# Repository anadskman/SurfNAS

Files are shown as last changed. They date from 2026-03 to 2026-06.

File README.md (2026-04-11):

# SurfNAS
A simple NAS ran by a raspberry pi

## How To Run
To Use this youll have to run a few commands in terminal first and download Raspberry Pi OS

### Install Libraries
Install [Raspberry Pi OS](https://downloads.raspberrypi.com/raspios_arm64/images/raspios_arm64-2025-12-04/2025-12-04-raspios-trixie-arm64.img.xz)
Open Terminal and Run
```
sudo apt update
sudo apt install python3-pip git
```
Then  Install Libraries
```
pip3 install adafruit-circuitpython-neopixel
pip3 install adafruit-circuitpython-ssd1306
pip3 install psutil
pip3 install pillow
```
This will Control
- OLED
- RGB LED
- system stats

### Enable I2C for the OLED
Run
```
sudo raspi-config
```
Then
```
Interface Options
→ I2C
→ Enable
```

### Run the Firmware
Make sure youve install [Nano SurfNAS.py](https://github.com/anadskman/SurfNAS/blob/main/Software/nano%20surfnas.py)

```
python3 surfnas.py
```
This Should Happen
- OLED showing stats
- LED changing color
- button shuts down system

### Start It Automatically
Create a systemd service
```
sudo nano /etc/systemd/system/surfnas.service
```
Paste
```
[Unit]
Description=SurfNAS Display Service
After=multi-user.target

[Service]
ExecStart=/usr/bin/python3 /home/pi/surfnas.py
Restart=always
User=pi

[Install]
WantedBy=multi-user.target
```
Enable It
```
sudo systemctl enable surfnas
sudo systemctl start surfnas
```
### What SurfNAS Should Show
OLED screen:
- SurfNAS
- CPU: 23%
- RAM: 41%
- Disk: 18%

LED:
| **Color** | **Meaning**
| :---: | :---:
| Green	| normal
| Orange | moderate load
| Red	heavy | load

Button:
- Power Control

## BOM
| Name | Description | URL | QTY | Price(€)
| :--: | :---: | :-: | :-: | :-----:
| Raspberry Pi Zero 2 WH | To Run the Server | [Amazon](https://www.amazon.ie/Raspberry-Pi-Zero-2-WH/dp/B0DB2JBD9C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) | 1 | 24.55
| MicroSD Card | 32GB | [Aliexpress](https://www.aliexpress.com/item/1005005262472106.html) | 1 | 6.66
| SSD | 128GB USB 3.0 | [Amazon](https://www.amazon.ie/gp/product/B0C1SD95B7/ref=ox_sc_act_title_2?smid=A22S87YMRWR0XZ&psc=1) | 1 | 20.99
| OLED | 0.96 I2C | [Aliexpress](https://www.aliexpress.com/item/1005006141235306.html) | 1 | 2.63
| Fan | 30mm Cooling Fan | [Amazon](https://www.amazon.ie/gp/product/B0DGG94SVD/ref=ox_sc_act_title_1?smid=A2LZP99XORN4MN&psc=1) | 1 | 5.78
| Button | Red Push Button 2 Pin | [Aliexpress](https://www.aliexpress.com/item/10000274959292.html) | 1 | 1.61
| RGB LED | SK6812MINI-E | Owned - Reuse From Hackpad Kit | 1 | 0.00
| Heat Sink | Blue kit | [Aliexpress](https://www.aliexpress.com/item/1005003083830470.html) | 1 | 2.36
| USB Adapter | C to Micro | [Amazon](https://www.amazon.ie/gp/product/B08WM1ZFZR/ref=ox_sc_act_title_2?smid=A2QHQAREJ10JUZ&psc=1) | 1 | 3.66
|  |  |  | Shipping | 4.89
|  |  |  | Total | 73.13

## Images
| Schematic | Case | Finished Look
| :---: | :---: | :---:
|  |  | 
)

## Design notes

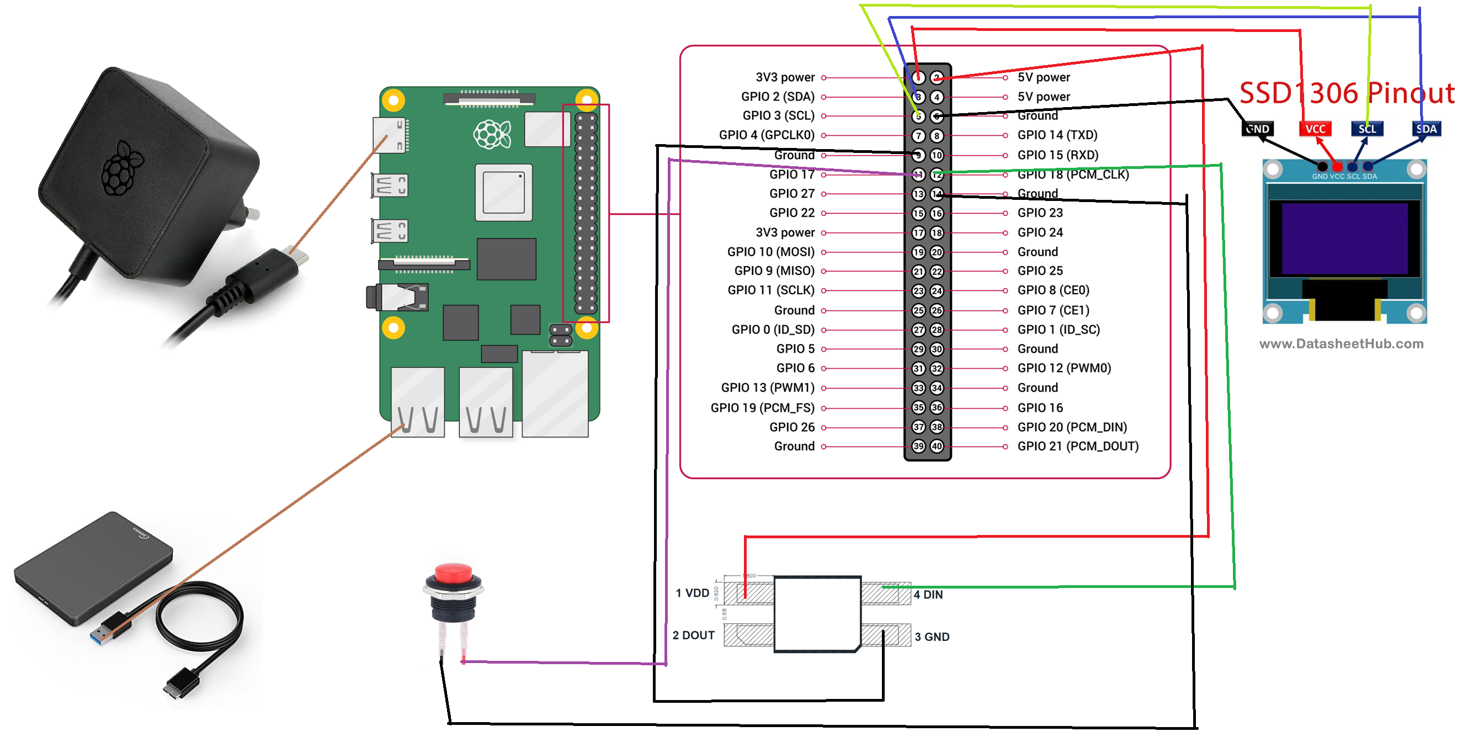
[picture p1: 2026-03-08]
SurfNAS diagram.png

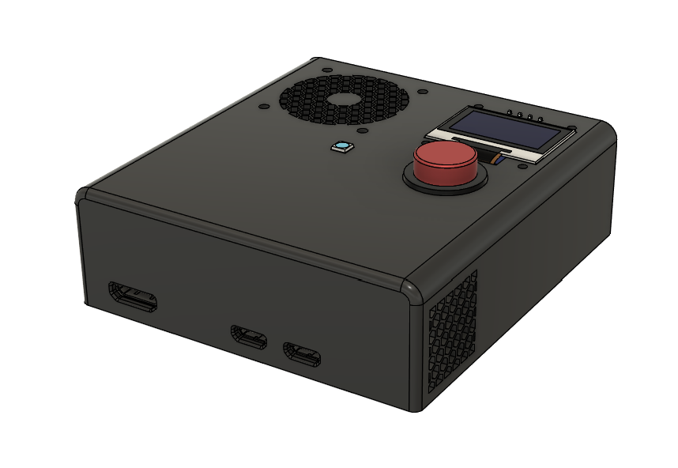
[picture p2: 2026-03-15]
Screenshot 2026-03-15 230135.png

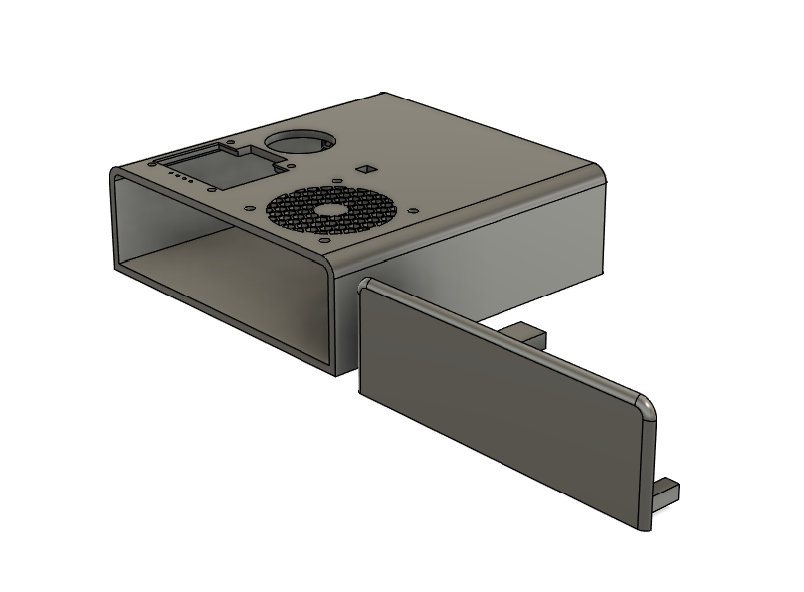
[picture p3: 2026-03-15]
Screenshot 2026-03-15 224113.png

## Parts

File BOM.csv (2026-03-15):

Name | Description | URL | Qty | Price(€)
Raspberry Pi Zero 2 WH | To Run the Server | https://www.amazon.ie/Raspberry-Pi-Zero-2-WH/dp/B0DB2JBD9C?s=electronics | 1 | 24.55
MicroSD Card | 32GB | https://www.aliexpress.com/item/1005005262472106.html | 1 | 6.66
SSD | 128GB USB 3.0 | https://www.amazon.ie/gp/product/B0C1SD95B7/ref=ox_sc_act_title_2?smid=A22S87YMRWR0XZ&psc=1 | 1 | 20.99
OLED | 0.96 I2C | https://www.aliexpress.com/item/1005006141235306.html | 1 | 2.63
Fan | 30mm Cooling Fan | https://www.amazon.ie/gp/product/B0DGG94SVD/ref=ox_sc_act_title_1?smid=A2LZP99XORN4MN&psc=1 | 1 | 5.78
Button | Red Push Button 2 Pin | https://www.aliexpress.com/item/10000274959292.html | 1 | 1.61
RGB LED | SK6812MINI-E | Owned - Reuse From Hackpad Kit | 1 | 0.00
Heat Sink | Blue kit | https://www.aliexpress.com/item/1005003083830470.html | 1 | 2.36
USB Adapter | C to Micro | https://www.amazon.ie/gp/product/B08WM1ZFZR/ref=ox_sc_act_title_2?smid=A2QHQAREJ10JUZ&psc=1 | 1 | 3.66
Shipping |  |  | 1 | 4.89
Total |  |  | 1 | 73.13

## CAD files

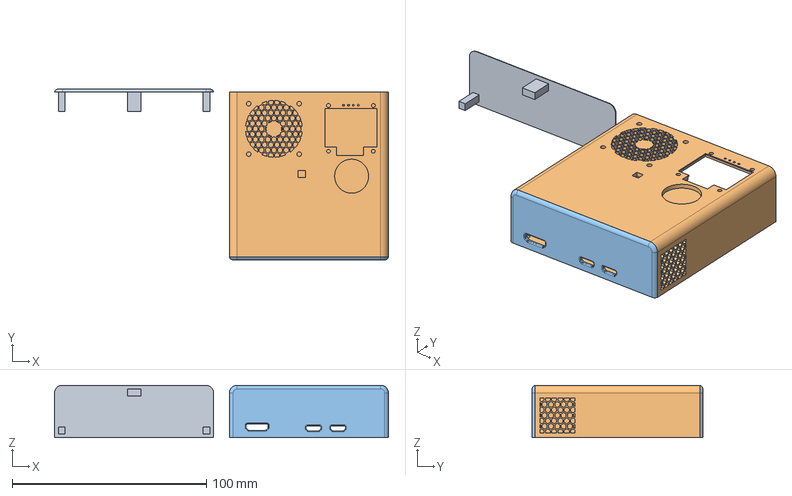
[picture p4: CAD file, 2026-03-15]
CAD/SurfNAS.step
172.0 x 88.0 x 27.0 mm

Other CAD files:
CAD/SurfNAS.f3z
CAD/SurfNAS.stl

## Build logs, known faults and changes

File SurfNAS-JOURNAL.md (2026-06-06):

<!--
  This journal is auto generated by Stasis.
-->

# 4/11/2026 6 PM - Finished Build

_Time spent: 2.333333333333333h_

I soldered all of the pins to the rpi.
I was following pictures of the pinout for the pi to make sure i wasnt wiring wrong.



I soldered the oled first and tested it but it wasnt turning on, turns out i wired the scl and sda backwards so i 
switched them around and it worked fine.
Then i connected the button and fan.
i made the ports too small so i melted them bigger.
then i screwed everything on, superglued together and put on heatsinks.



Heres my demo link:
https://youtube.com/shorts/sX4HMbiHAks?feature=share




# 4/10/2026 5 PM - Redesigned case

_Time spent: 1.5h_

i started by adding a rectangle the size of the rpi and and another around it.
The outside one will be the case.
I added holes for screw mounts.
I also added a honeycomb pattern throughout for both design and airflow.



After this i added a 70 deg box ontop of the rpi compartment.



this box will hold the oled and stop button.
on the side of this box and part of the bottom box i added a placement for the fan.
For the oled cutout i made sure to leave an extra space for the ribbion.



Then i added the holes for the usb ports but i saw i made the orginal rpi case too small so i redesign it.
lastly i add the final covering on the top, i made it honeycomb for airflow.



I cut parts up and layed them out to be printed








# 4/8/2026 8 PM - Made firmware for oled and button

_Time spent: 2h_

Plugged in the OLED and got it detected over I2C. Installed the required Python libraries, but because of the new Python restrictions, I had to make a virtual environment to run everything properly.

After that, I wrote a script to control the OLED. It displays useful info like the device name (SurfNAS), CPU temperature, website status, and the local IP address. It updates every few seconds so it’s basically a live status screen for the server.

For cooling, the fan is just wired straight to 5V and GND so it stays on all the time. It’s quiet enough so there’s no need to control it with software.

I also added a button connected to a GPIO pin, which runs a script to safely shut down the Pi when pressed. This avoids just cutting power and potentially corrupting the system.


I also made it so these auto run at boot.



# 4/8/2026 4 PM - Finished software

_Time spent: 4h_

So I changed back to Lite 32bit OS and i couldnt get it to connected to wifi.
I connected it to my hotspot to check if it would connect and it did.
the problem ended up being, i had to use IPv6 not 4
After this i ran
`
sudo apt update
sudo apt upgrade -y
`
then I checked if the ssd was being dected and it wasnt.
I ended up having to use my own 1tb ssd but i was careful not to formate it.

I went through the entire setup process and then i had my folders made "website", "other"
I figured out my RPI's IPv4 and then i setup access to the ssd in windows explorer


I tried putting my own files in a folder but then it was saying not enough storage so i ended up just formating the ssd.

After all that i was done, i uploaded my website to my folder and if i go to http://192.168.100.105
ill see my portfolio website





# 4/7/2026 10 PM - Tried to setup RPI

_Time spent: 4h_

I started off trying to get the Raspberry Pi Zero 2 W running for SurfNAS.

I started off trying to run with Raspberry Pi OS Lite, flashed it to the SD card and tried to SSH in, but couldn’t connect at all.

At the start, the rpi wasnt turning on. The LED flashed once. Turned out the power cable was the problem, it wasn’t actually delivering proper power. Switched cables and it finally powered on properly.

After that, tried connecting over SSH using .local hostnames but nothing worked.

Then moved to checking IPs using arp -a, and i think it started working but then when i went to setup the ssd(my usb flash drive) that wasnt working.
So after looking through my parts descriptions it seems like everything should be working but its not.


I ended up deciding to go with DietPi instead of Raspberry Pi OS Lite since it’s lighter and better for a NAS. I Flashed DietPi to the SD card.

Then I Ran into problems setting up SSH access because, i coudnt set a password initially, i tried using userconf.txt but that didnt work
added ssh file to enable SSH

Still couldn’t connect though.

Then i realized the Pi wasn’t showing up on the network at all.

so i tried configuring Wifi using:
dietpi.txt, and dietpi-wifi.txt

Even after that, Pi still didn’t show in arp -a. Only IP that worked was 192.168.100.1, which turned out to just be the router.

At this point, the power is working, SD card is flashing correctly, Config files are in place

But the Pi still isn’t connecting to WiFi, so it’s not getting an IP and can’t be SSH’d into yet.

I think ill be going back to the first setup, running with lite os and ask in #statis if anyone knows why the usb isnt being detected





# 3/15/2026 11 PM - Remade Case, Updated BOM

_Time spent: 3h_

I remade the case to match the new rpi..

I changed the fan from a 40mm to 30mm to save space.

Then I remembered the ssd is usb C not micro usb so i found a cheap adapter to connect it to the board.

I made it so it opens from the back.


I didnt change the schematic because the pins are nearly the same layout.











# 3/9/2026 5 PM - Made BOM , Software and Github

_Time spent: 4h_

I made up The Software which is mainly just running scripts in Terminal and setting up Raspberry Pi OS.

Then I Made the tutorial in the [readme.md](https://github.com/anadskman/SurfNAS/blob/main/README.md) and I uploaded everything to github


After Everything was Uploaed i Made the BOM. I Found every Part i Needed on aliexpress and amazon and then wrote everything in a table for the readme.
Then I Created BOM.csv


Lastly I Uploaded Images of the Schematic, Case, And Assembly Design.






# 3/8/2026 10 PM - Made the Case

_Time spent: 6h_

### This took a while.



I started by making the parts ill have, the neo case, SSD, button, raspberry pi, oled and led.
For the pi, oled, and led I imported that but the rest i made just basic shapes for size demonstration.





I was originally gonna have a argon neo case for the pi but i Realised that would just waste money and time when i could just 3d print the case and add a tiny fan instead, so that's what i did.



I added a honeycomb pattern on top for airflow.
I finished making all the sides of the case with holes for ports and i decided to add another gap of honeycomb for airflow as it was an empty space.


Lastly I made the USB panel. I added corners to them so they slide into the case keeping it there.









# 3/8/2026 1 PM - I made up the Schematic for this project (Note: I did this and the planning and  forgot to journal)

_Time spent: 3h_

I found every part need for the NAS and put them in paint.
after i had every part i drew lines to show their wiring.

SurfNAS diagram

I didnt include the case/fan because that attaches on to the board.



Im using the extra Leds that came with the hackpad kit to save money and time.

SurfNAS Case plan:

**Front Panel**
[ OLED screen ]
     ● RGB LED
[ Power Button ]

**Inside Case**
 ┌───────────────────┐
 │ Raspberry Pi 4    │
 │                   │
 │ microSD (bottom)  │
 │ Fan on top        │
 │ GPIO wires → OLED │
 │ GPIO wires → LED  │
 │ GPIO wires → BTN  │
 └───────────────────┘
        │
        │ USB 3.0
        │
     SSD Drive

**Top/Bottom Panels**
Honeycomb or Line pattern




# 3/8/2026 1 PM - Plan All the Items, The Goals, Design

_Time spent: 2h_

# Whats inside

### **Parts:**
- Raspberry Pi 4 Model B
- USB SSD (ideally 500gb+)
- 32GB microSD card
- Raspberry Pi case with fan
- official Pi power adapter
- Ethernet cable
- OLED Display
- RGB LED
- Power Button

### **Software**
**OS:**
- Raspberry Pi OS

**NAS software:**
- OpenMediaVault

# What Can it Do?
- backup my PC
- store files for my house
- block ads on WiFi
- run small apps
- host websites
- monitor network
- dashboard webpage

# Approx Cost
| Item | Cost(€) |
| ---- | --- |
| Raspberry Pi 4 | 90 |
| SSD | 50 |
| microSD | 10 |
| case/fan | 15 |
| power Supply | 10 |
| oled | 6 |
| led | 3 |
| buttons | 2 |
| **total** | **~180** |








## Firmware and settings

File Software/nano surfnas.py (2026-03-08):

import time
import board
import neopixel
import psutil
import digitalio
import busio
from PIL import Image, ImageDraw, ImageFont
import adafruit_ssd1306
import os

pixels = neopixel.NeoPixel(board.D18, 1)

button = digitalio.DigitalInOut(board.D17)
button.direction = digitalio.Direction.INPUT
button.pull = digitalio.Pull.UP

i2c = busio.I2C(board.SCL, board.SDA)
display = adafruit_ssd1306.SSD1306_I2C(128, 64, i2c)

width = display.width
height = display.height

image = Image.new("1", (width, height))
draw = ImageDraw.Draw(image)
font = ImageFont.load_default()

while True:

    cpu = psutil.cpu_percent()
    ram = psutil.virtual_memory().percent
    disk = psutil.disk_usage("/").percent
    ip = os.popen("hostname -I").read().strip()

    if cpu < 40:
        pixels[0] = (0, 255, 0)
    elif cpu < 80:
        pixels[0] = (255, 150, 0)
    else:
        pixels[0] = (255, 0, 0)

    draw.rectangle((0,0,width,height), outline=0, fill=0)

    draw.text((0,0), "SurfNAS", font=font, fill=255)
    draw.text((0,15), f"CPU: {cpu}%", font=font, fill=255)
    draw.text((0,30), f"RAM: {ram}%", font=font, fill=255)
    draw.text((0,45), f"Disk: {disk}%", font=font, fill=255)

    display.image(image)
    display.show()

    if not button.value:
        os.system("sudo shutdown now")

    time.sleep(2)
